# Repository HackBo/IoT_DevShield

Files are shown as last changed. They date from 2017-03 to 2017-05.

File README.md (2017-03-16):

# A Developement Shield for IoT proyects

A shield that include Sensors, Actuators And Comm Modules 'ready to work'.

The shield use the 'Arduino Socket' that accomplish the compatibility not only with Arduino boards also many other boards that use the 
same 'Arduino Socket' form.

The list of the actual components are:

## Sensors
 
 * MMA8452Q (Accelerometer)
 * LM35 (Temperature)
 * DHT11* (Humidity And Temperature)
 * SS39AT (Hall Effect)
 * SS351AT (Hall Effect)
 * LDR (Light)
 * Potenciometer
 * Switch

## Actuators

 * RGB LED
 * Buzzer
 * Rele
 * High Power Mosfet
 * Servo Motor*
 * LCD OLED*

## COMM Modules

 * HC05 (Bluetooth)
 * TSOP(IR Rx)
 * IR LED (IR Tx)
 * ESP-01* (WiFi)
 * NRF24L01+* (2.4GHz RF)

## Others

 * 24LC256 (EEPROM 256Kb)
 * DS1307 (RTC)

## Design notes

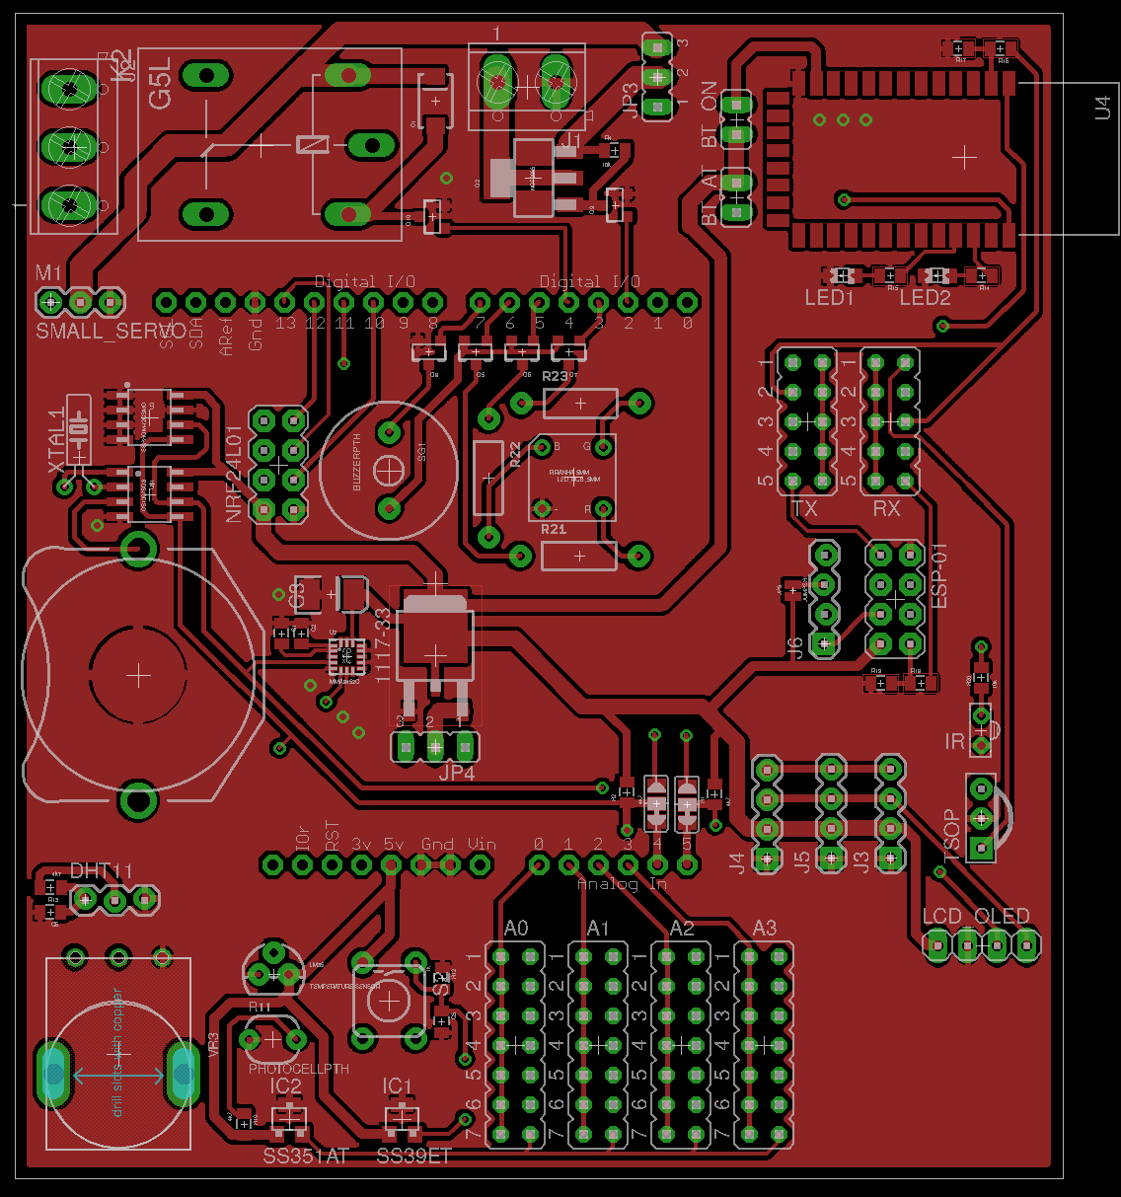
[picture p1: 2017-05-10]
img/Impreso_top.png

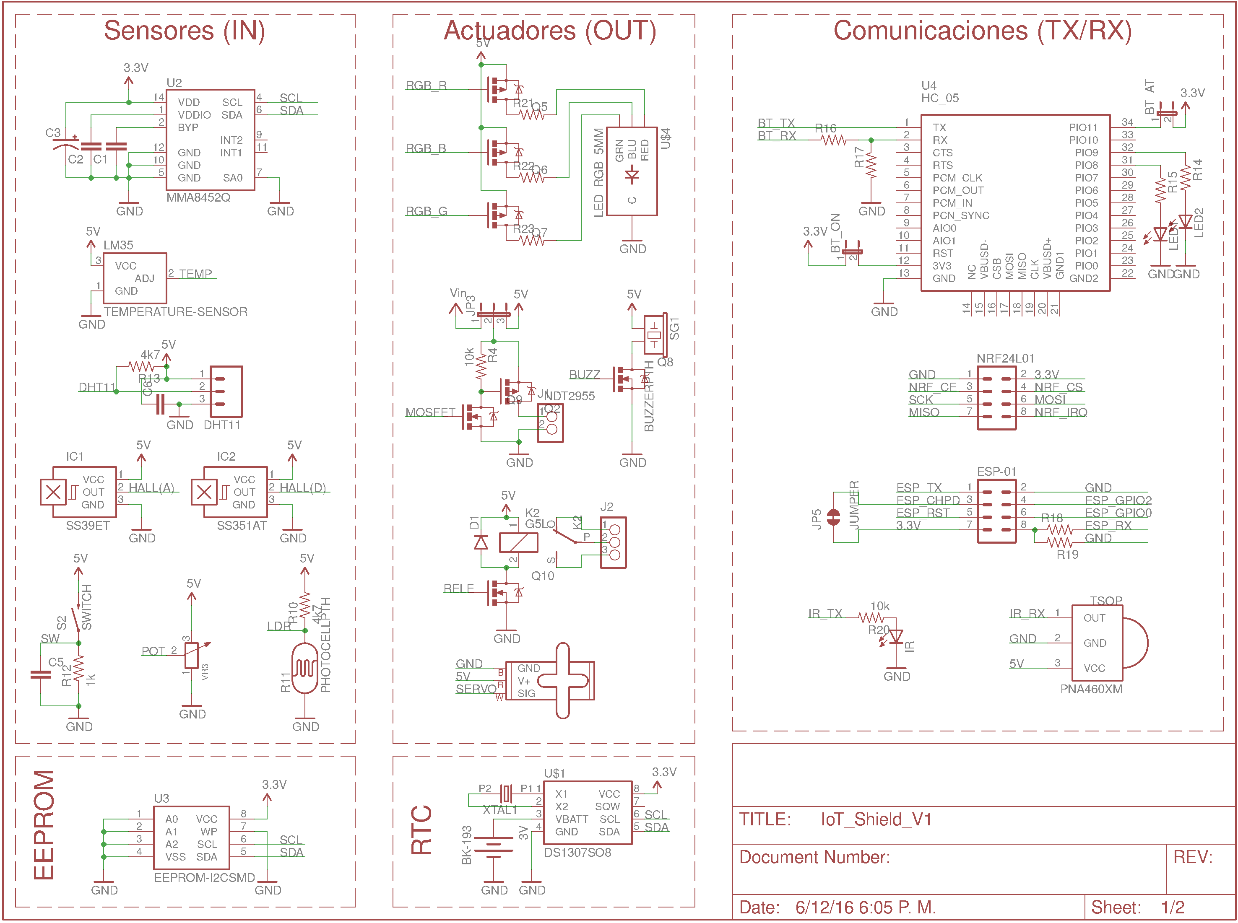
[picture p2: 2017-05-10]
img/Esquematico_Hoja1.png

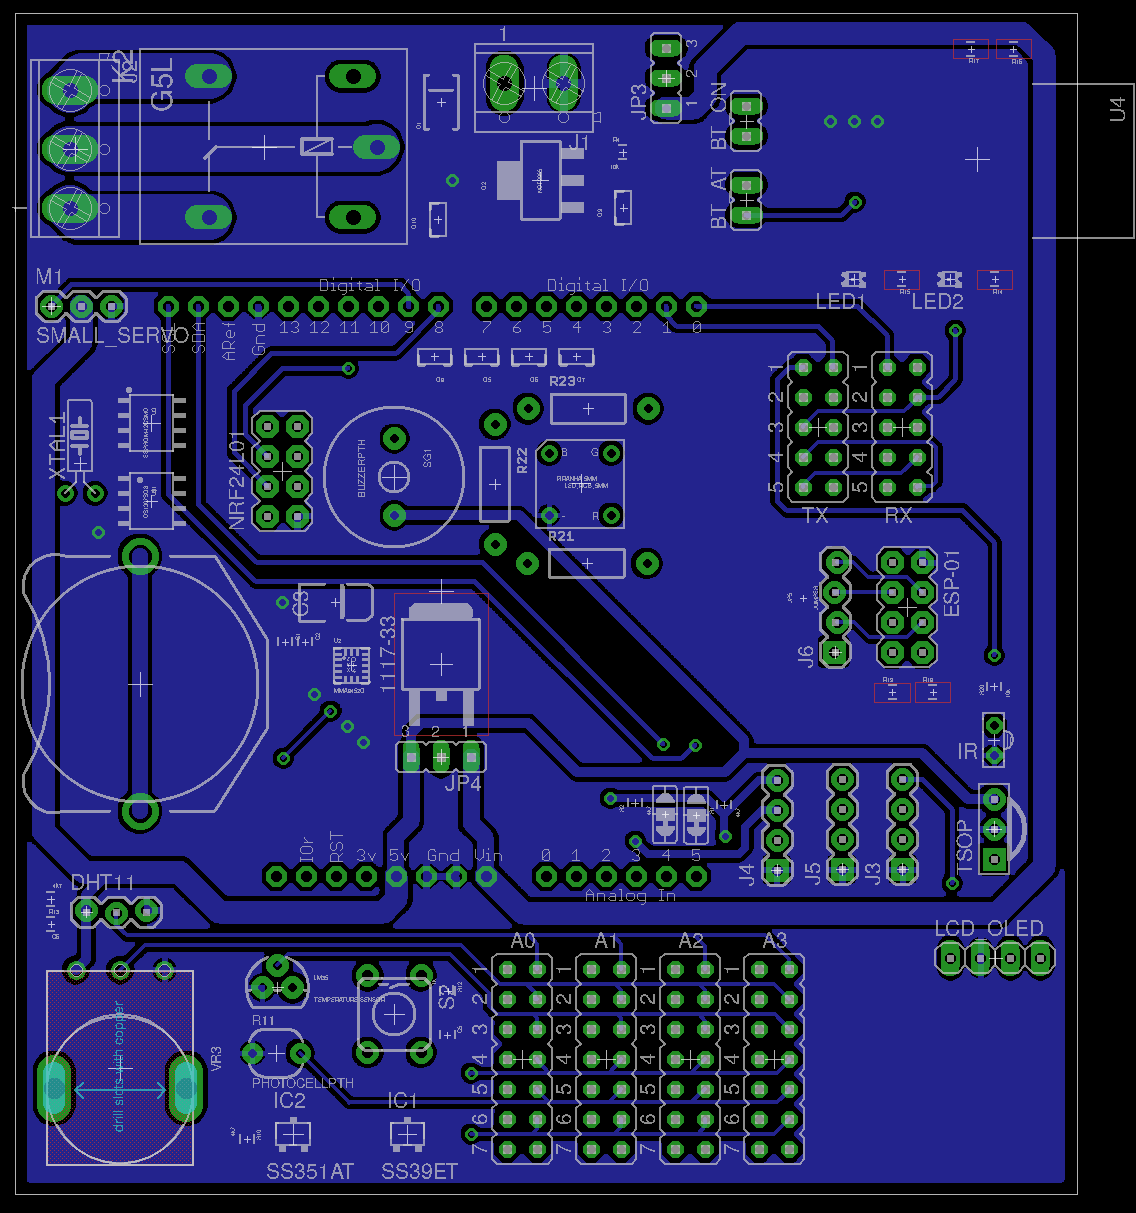
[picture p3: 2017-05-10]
img/Impreso_bottom.png

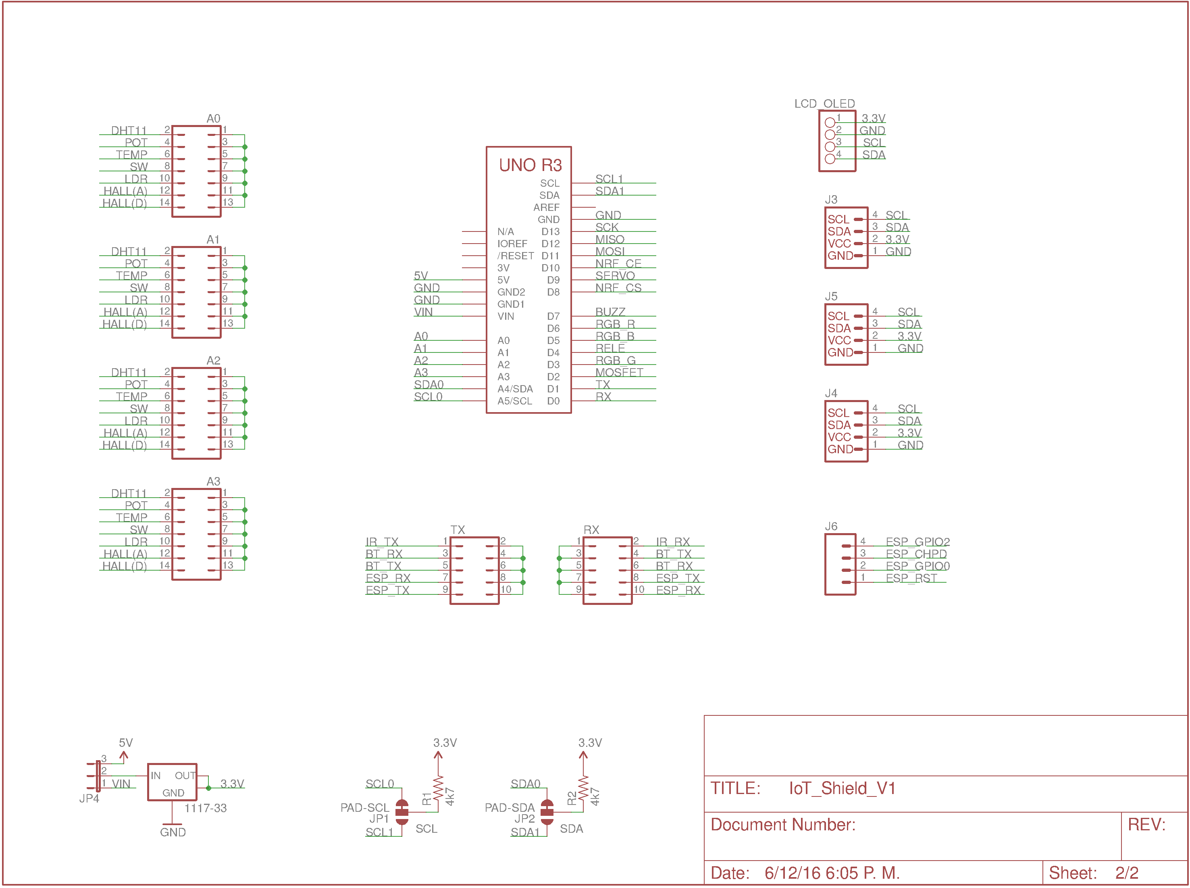
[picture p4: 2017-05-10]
img/Esquematico_Hoja2.png

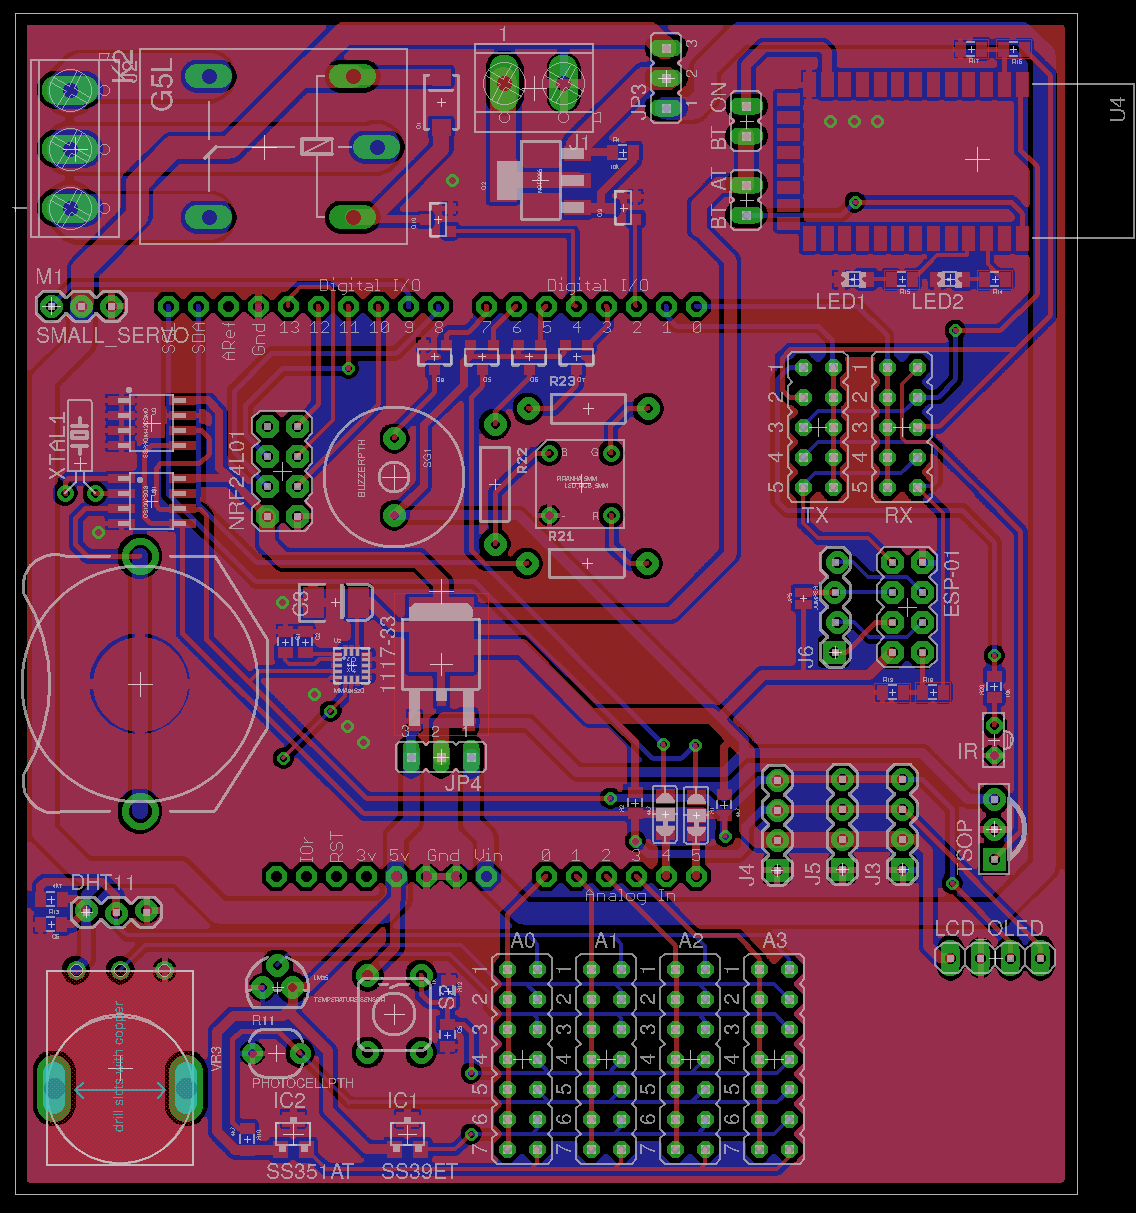
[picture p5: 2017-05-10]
img/Impreso_all.png

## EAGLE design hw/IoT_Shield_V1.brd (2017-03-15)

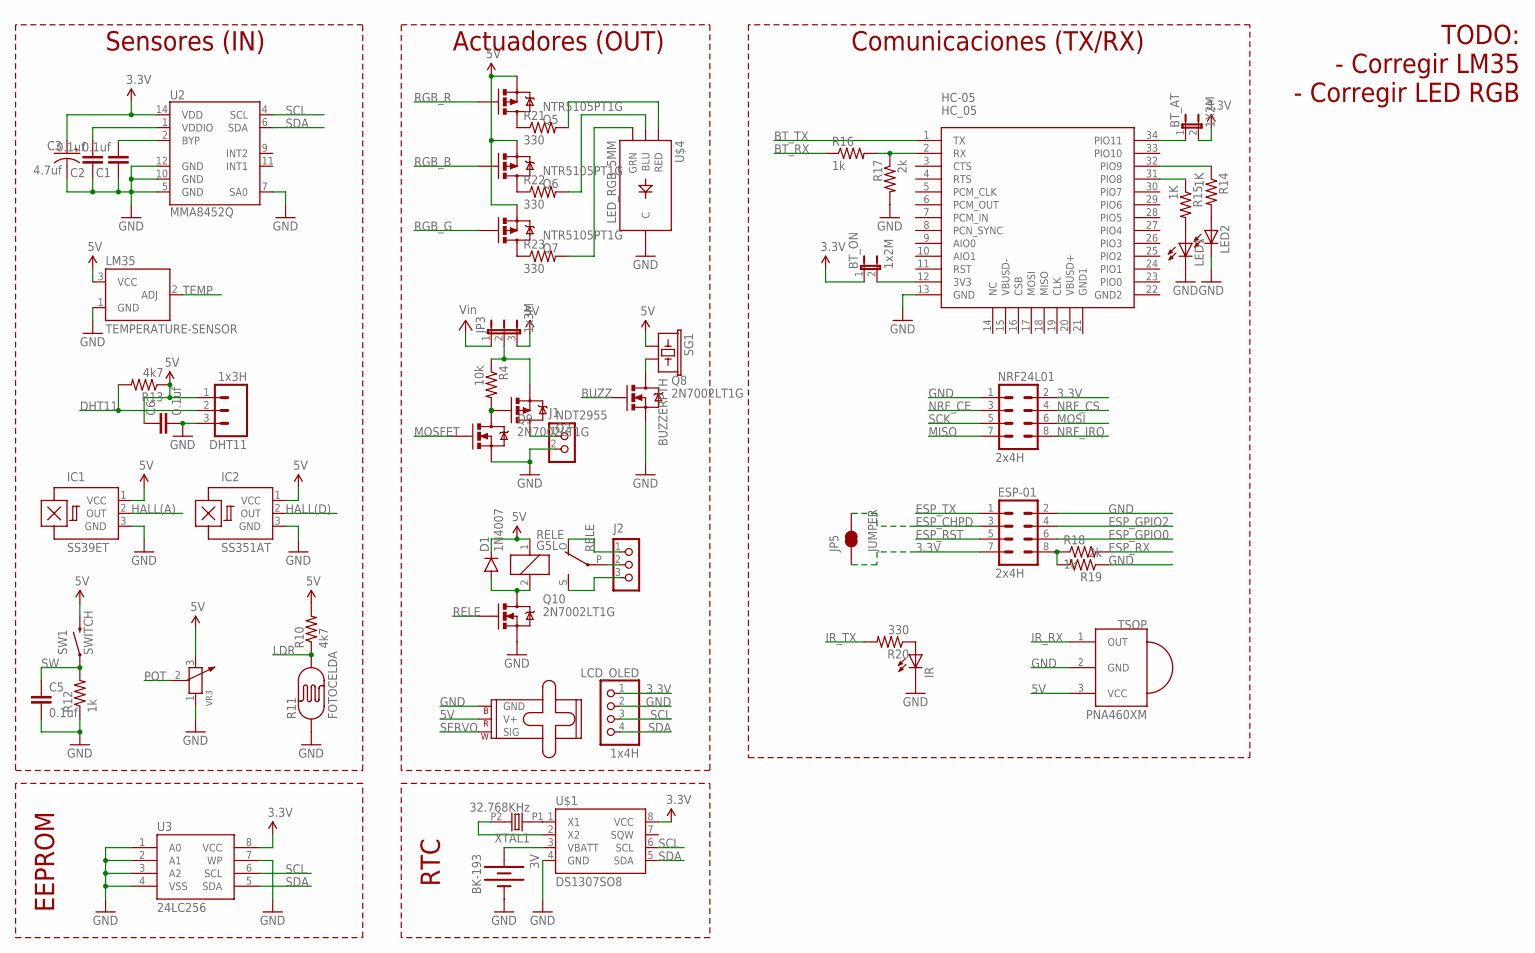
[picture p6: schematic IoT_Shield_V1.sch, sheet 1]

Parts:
3V: BK-193; BATTERY-20MMTH
BT_AT: 1X2M; JP1
BT_ON: 1x2M; JP1
C1, C2, C5, C6: 0.1uf; 0805
C3: 4.7uf; EIA3528-KIT
D1: 1N4007; SMA-DIODE
DHT11: 1x3H; 1X03_LOCK
ESP-01: 2x4H; 2X4
HC-05: HC_05; BLUETOOTH_SMD
IC1: SS39ET; SOT23-W
IC2: SS351AT; SOT23-W
IR: LEDIRL80A; IRL80A
J1: CON_TERMINAL_BLOCK_02-5MM; TERMINAL_BLOCK_2P_5
J2: CON_TERMINAL_BLOCK_03-5MM; TERMINAL_BLOCK_3P_5
JP3: 1x3M; JP2
JP5: JUMPER; PAD-JUMPER-2-NC_BY_TRACE_NO_SILK
LCD_OLED: 1x4H; 1X04
LED1, LED2: LEDCHIPLED_0805; CHIPLED_0805
LM35: TEMPERATURE-SENSOR; TO-92
NRF24L01: 2x4H; 2X4
Q2: NDT2955; SOT223
Q5, Q6, Q7: NTR5105PT1G; SOT23-3
Q8, Q9, Q10: 2N7002LT1G; SOT23-3
R4: 10k; 0805
R10, R13: 4k7; 0805
R11: FOTOCELDA; PHOTOCELL
R12, R16, R18: 1k; 0805
R14, R15: 1K; 0805
R17, R19: 2k; 0805
R20, R21, R22, R23: 330; 1206
RELE: G5L; G5LE
SERVO: 1X3M; 1X03
SG1: BUZZERPTH; BUZZER-12MM
SW1: SWITCH; TACTILE-PTH
TSOP: PNA460XM
U2: MMA8452Q; QFN-16_0.5MM
U3: 24LC256; SO08
U$1: DS1307SO8; SO08
U$4: LED_RGB_5MM; LED_PIRANHA_5MM
VR3: RES-ADJ'WH121-1'; ADJR2+3P-16.0X12.0X18.0MM
XTAL1: 32.768KHz; TC-26

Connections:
3.3V: BT_AT.2, BT_ON.1, C3.A (+), ESP-01.7, JP5.1, LCD_OLED.1, NRF24L01.2, U2.14 (VDD), U3.8 (VCC), U$1.8 (VCC); also elsewhere on the board
5V: C6.1, D1.C, DHT11.1, IC1.1 (VCC), IC2.1 (VCC), JP3.3, LM35.3 (VCC), Q5.2 (S), Q6.2 (S), Q7.2 (S), R10.2, R13.1, RELE.1, SERVO.2 (V+), SG1.+ (1), SW1.3 (2), TSOP.3 (VCC), VR3.3; also elsewhere on the board
BT_RX: R16.1; also elsewhere on the board
BT_TX: HC-05.1 (TX); also elsewhere on the board
BUZZ: Q8.1 (G); also elsewhere on the board
DHT11: DHT11.2, R13.2; also elsewhere on the board
ESP_CHPD: ESP-01.3, JP5.2; also elsewhere on the board
ESP_GPIO0: ESP-01.6; also elsewhere on the board
ESP_GPIO2: ESP-01.4; also elsewhere on the board
ESP_RST: ESP-01.5; also elsewhere on the board
ESP_RX: R18.2; also elsewhere on the board
ESP_TX: ESP-01.1; also elsewhere on the board
GND: 3V.P1- (-), C1.1, C2.1, C3.C (-), C5.2, C6.2, DHT11.3, ESP-01.2, HC-05.13 (GND), IC1.3 (GND), IC2.3 (GND), IR.K (C), J1.2, LCD_OLED.2, LED1.C, LED2.C, LM35.1 (GND), NRF24L01.1, Q8.2 (S), Q9.2 (S), Q10.2 (S), R11.1, R12.1, R17.2, R19.1, SERVO.3 (GND), TSOP.2 (GND), U2.5 (GND), U2.7 (SA0), U2.10 (GND), U2.12 (GND), U3.1 (A0), U3.2 (A1), U3.3 (A2), U3.4 (VSS), U3.7 (WP), U$1.4 (GND), U$4.- (C), VR3.1; also elsewhere on the board
HALL(A): IC1.2 (OUT); also elsewhere on the board
HALL(D): IC2.2 (OUT); also elsewhere on the board
IR_RX: TSOP.1 (OUT); also elsewhere on the board
IR_TX: R20.2; also elsewhere on the board
LDR: R10.1, R11.2; also elsewhere on the board
MISO: NRF24L01.7; also elsewhere on the board
MOSFET: Q9.1 (G); also elsewhere on the board
MOSI: NRF24L01.6; also elsewhere on the board
unnamed: U$1.2 (X2), XTAL1.P2 (2)
unnamed: U$1.1 (X1), XTAL1.P1 (1)
unnamed: 3V.P2+ (+), 3V.P3+ (+), U$1.3 (VBATT)
unnamed: C1.2, U2.2 (BYP)
unnamed: C2.2, U2.1 (VDDIO)
unnamed: J1.1, Q2.2 (D), Q2.4 (D)
unnamed: Q8.3 (D), SG1.- (2)
unnamed: Q2.1 (G), Q9.3 (D), R4.2
unnamed: D1.A, Q10.3 (D), RELE.2
unnamed: R23.2, U$4.G (GRN)
unnamed: R22.2, U$4.B (BLU)
unnamed: R21.2, U$4.R (RED)
unnamed: JP3.2, Q2.3 (S), R4.1
unnamed: BT_ON.2, HC-05.12 (3V3)
unnamed: HC-05.32 (PIO9), R14.1
unnamed: HC-05.31 (PIO8), R15.1
unnamed: LED1.A, R15.2
unnamed: LED2.A, R14.2
unnamed: HC-05.2 (RX), R16.2, R17.1
unnamed: ESP-01.8, R18.1, R19.2
unnamed: Q5.3 (D), R21.1
unnamed: BT_AT.1, HC-05.34 (PIO11)
unnamed: Q6.3 (D), R22.1
unnamed: Q7.3 (D), R23.1
unnamed: IR.A, R20.1
NRF_CE: NRF24L01.3; also elsewhere on the board
NRF_CS: NRF24L01.4; also elsewhere on the board
NRF_IRQ: NRF24L01.8
POT: VR3.2; also elsewhere on the board
RELE: Q10.1 (G); also elsewhere on the board
RELE_COMM: J2.2, RELE.P
RELE_NC: J2.1, RELE.O
RELE_NO: J2.3, RELE.S
RGB_B: Q6.1 (G); also elsewhere on the board
RGB_G: Q7.1 (G); also elsewhere on the board
RGB_R: Q5.1 (G); also elsewhere on the board
SCK: NRF24L01.5; also elsewhere on the board
SCL: LCD_OLED.3, U2.4 (SCL), U3.6 (SCL), U$1.6 (SCL); also elsewhere on the board
SDA: LCD_OLED.4, U2.6 (SDA), U3.5 (SDA), U$1.5 (SDA); also elsewhere on the board
SERVO: SERVO.1 (SIG); also elsewhere on the board
SW: C5.1, R12.2, SW1.1; also elsewhere on the board
TEMP: LM35.2 (ADJ); also elsewhere on the board
VIN: JP3.1; also elsewhere on the board

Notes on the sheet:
Sensores (IN)
Actuadores (OUT)
Comunicaciones (TX/RX)
RTC
EEPROM
TODO: - Corregir LM35 - Corregir LED RGB

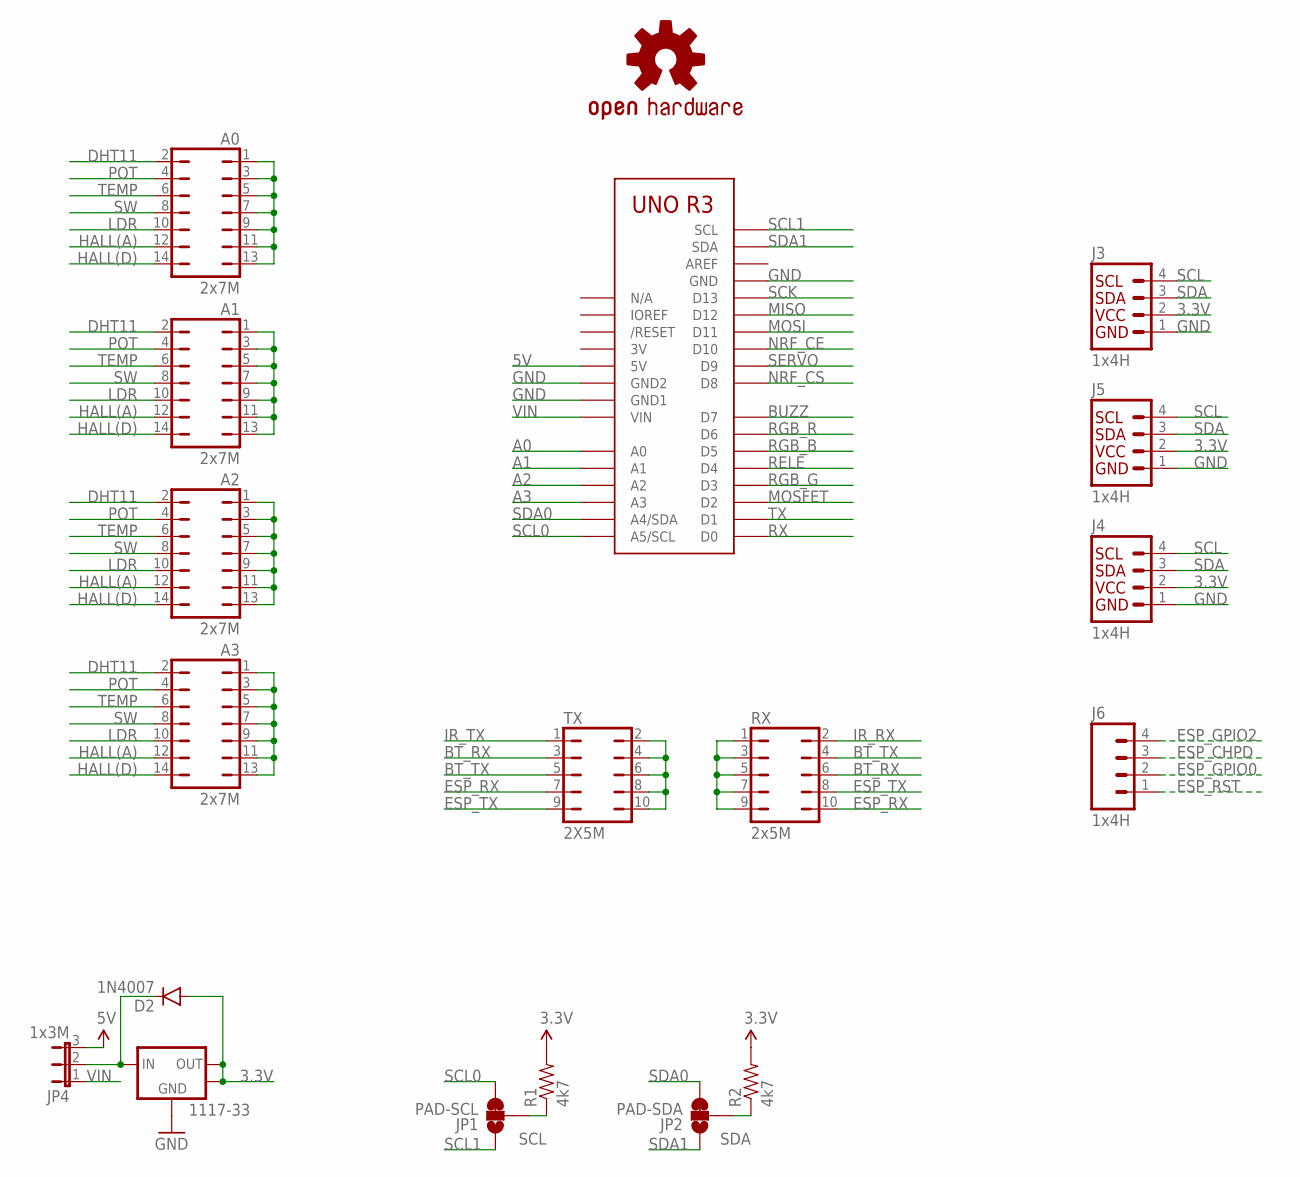
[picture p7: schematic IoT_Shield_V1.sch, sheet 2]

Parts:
1117-33: LV1117-33TO252; TO252
A0, A1, A2, A3: 2x7M; JP7Q
D2: 1N4007; SMA-DIODE
J3, J4, J5: 1x4H; 1X04
J6: 1x4H; 1X04_LOCK
JP1: PAD-SCL; PAD-JUMPER-3-2OF3_NC_BY_TRACE_YES_SILK_LARGE
JP2: PAD-SDA; PAD-JUMPER-3-2OF3_NC_BY_TRACE_YES_SILK_LARGE
JP4: 1x3M; JP2
LOGO1: OSHW-LOGOL-COPPER; OSHW-LOGO-L_COPPER
R1, R2: 4k7; 0805
RX: 2x5M; JP5Q
TX: 2X5M; JP5Q
U1: ARDUINOR3-DIMENSION; ARDUINOR3

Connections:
3.3V: 1117-33.2 (OUT), 1117-33.4 (OUT), D2.A, J3.2, J4.2, J5.2, R1.2, R2.2; also elsewhere on the board
3V: U1.3V
5V: JP4.3, U1.5V; also elsewhere on the board
A0: A0.1, A0.3, A0.5, A0.7, A0.9, A0.11, A0.13, U1.A0
A1: A1.1, A1.3, A1.5, A1.7, A1.9, A1.11, A1.13, U1.A1
A2: A2.1, A2.3, A2.5, A2.7, A2.9, A2.11, A2.13, U1.A2
A3: A3.1, A3.3, A3.5, A3.7, A3.9, A3.11, A3.13, U1.A3
BT_RX: RX.6, TX.3; also elsewhere on the board
BT_TX: RX.4, TX.5; also elsewhere on the board
BUZZ: U1.D7; also elsewhere on the board
DHT11: A0.2, A1.2, A2.2, A3.2; also elsewhere on the board
ESP_CHPD: J6.3; also elsewhere on the board
ESP_GPIO0: J6.2; also elsewhere on the board
ESP_GPIO2: J6.4; also elsewhere on the board
ESP_RST: J6.1; also elsewhere on the board
ESP_RX: RX.10, TX.7; also elsewhere on the board
ESP_TX: RX.8, TX.9; also elsewhere on the board
GND: 1117-33.1 (ADJ), J3.1, J4.1, J5.1, U1.GND, U1.GND1, U1.GND2; also elsewhere on the board
HALL(A): A0.12, A1.12, A2.12, A3.12; also elsewhere on the board
HALL(D): A0.14, A1.14, A2.14, A3.14; also elsewhere on the board
IR_RX: RX.2; also elsewhere on the board
IR_TX: TX.1; also elsewhere on the board
LDR: A0.10, A1.10, A2.10, A3.10; also elsewhere on the board
MISO: U1.D12; also elsewhere on the board
MOSFET: U1.D2; also elsewhere on the board
MOSI: U1.D11; also elsewhere on the board
unnamed: 1117-33.3 (IN), D2.C, JP4.2
NRF_CE: U1.D10; also elsewhere on the board
NRF_CS: U1.D8; also elsewhere on the board
POT: A0.4, A1.4, A2.4, A3.4; also elsewhere on the board
RELE: U1.D4; also elsewhere on the board
RGB_B: U1.D5; also elsewhere on the board
RGB_G: U1.D3; also elsewhere on the board
RGB_R: U1.D6; also elsewhere on the board
RX: RX.1, RX.3, RX.5, RX.7, RX.9, U1.D0
SCK: U1.D13; also elsewhere on the board
SCL: J3.4, J4.4, J5.4, JP1.2, R1.1; also elsewhere on the board
SCL0: JP1.3, U1.A5 (A5/SCL)
SCL1: JP1.1, U1.SCL
SDA: J3.3, J4.3, J5.3, JP2.2, R2.1; also elsewhere on the board
SDA0: JP2.3, U1.A4 (A4/SDA)
SDA1: JP2.1, U1.SDA
SERVO: U1.D9; also elsewhere on the board
SW: A0.8, A1.8, A2.8, A3.8; also elsewhere on the board
TEMP: A0.6, A1.6, A2.6, A3.6; also elsewhere on the board
TX: TX.2, TX.4, TX.6, TX.8, TX.10, U1.D1
VIN: JP4.1, U1.VIN; also elsewhere on the board

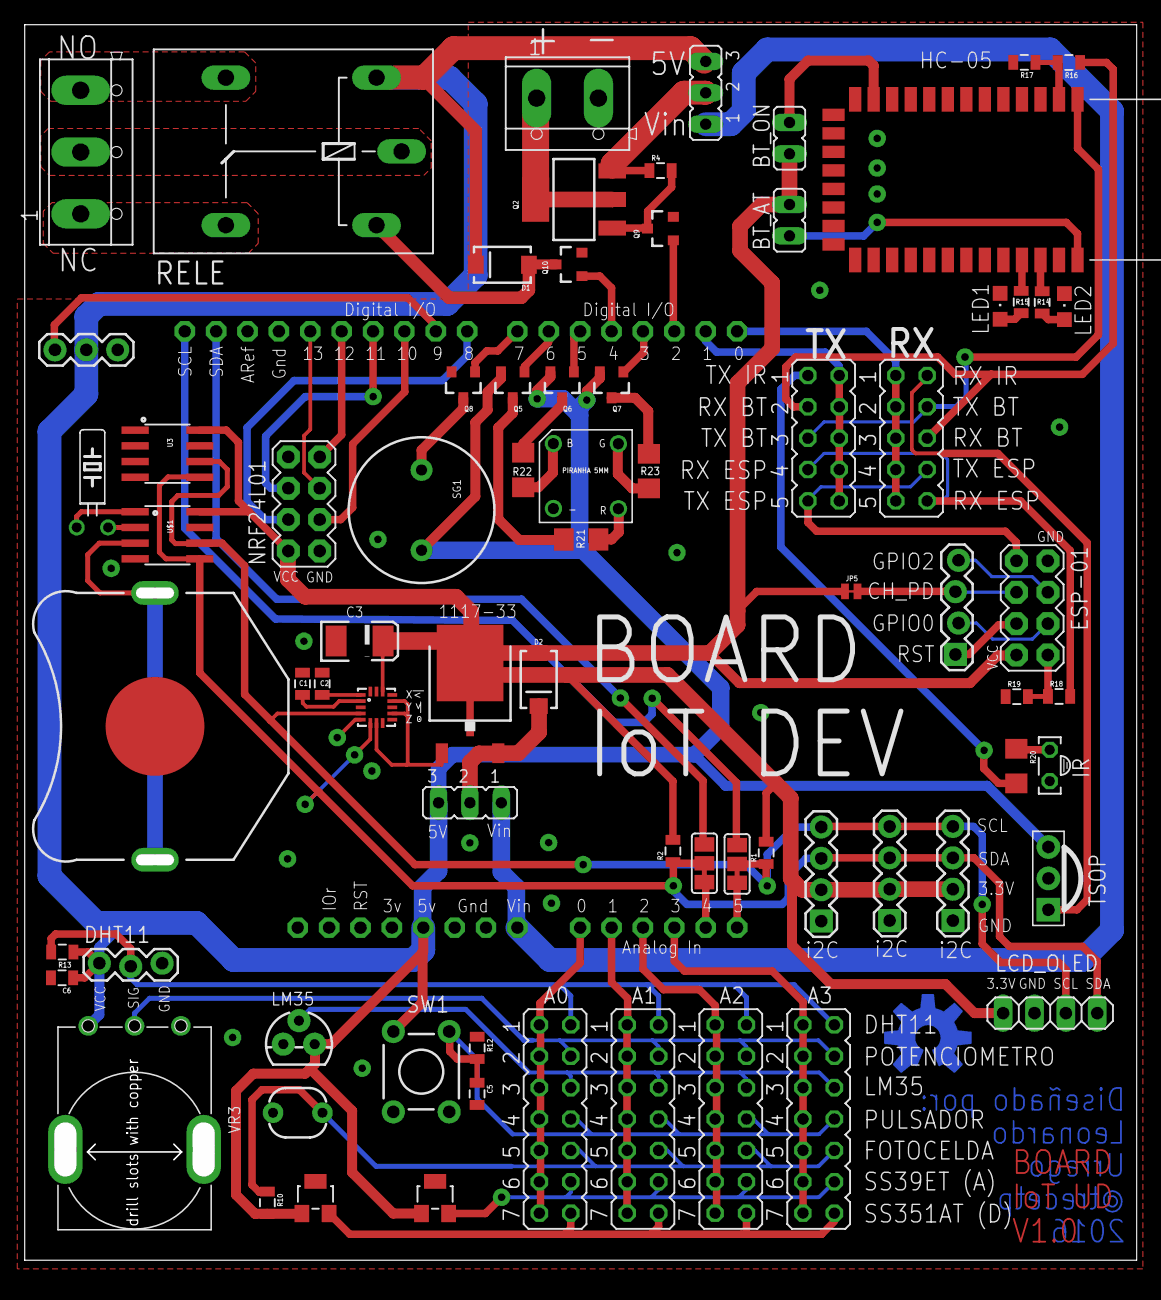
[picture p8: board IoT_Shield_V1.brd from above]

Board: 2 copper layers, 90.0 x 100.0 mm, 76 parts (1 on the bottom side), 74 nets.

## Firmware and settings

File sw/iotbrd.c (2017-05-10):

#include <Wire.h>
#include <RTClib.h>
#include <U8x8lib.h>
#include <SimpleDHT.h>
#include <Servo.h>


//Definiciones de pines

//Pines de salida
#define _OUT_LED_RGB_R_         5
#define _OUT_LED_RGB_G_         3
#define _OUT_LED_RGB_B_         6
#define _OUT_MOSFET_            2
#define _OUT_RELE_              4
#define _OUT_BUZZ_              7
#define _OUT_SERVO_             9

// Pines de Entrada
#define _IN_A0_POT_             A0
#define _IN_A2_POT_             A2
#define _IN_A0_LM35_            A0
#define _IN_A1_DHT11_           15



//Pines de Control
#define _NFR_CS_                8
#define _NFR_CE_                10

//Contantes de control
#define _LED_RGB_ON_            0
#define _LED_RGB_OFF_           1
#define _MOSFET_ON_             1
#define _MOSFET_OFF_            0
#define _BUZZ_ON_               1
#define _BUZZ_OFF_              0
#define _RELE_ON_               1
#define _RELE_OFF_              0



//MACROS
#define ledRGB_ON_R()   digitalWrite(_OUT_LED_RGB_R_, _LED_RGB_ON_)
#define ledRGB_ON_G()   digitalWrite(_OUT_LED_RGB_G_, _LED_RGB_ON_)
#define ledRGB_ON_B()   digitalWrite(_OUT_LED_RGB_B_, _LED_RGB_ON_)
#define ledRGB_OFF_R()  digitalWrite(_OUT_LED_RGB_R_, _LED_RGB_OFF_)
#define ledRGB_OFF_G()  digitalWrite(_OUT_LED_RGB_G_, _LED_RGB_OFF_)
#define ledRGB_OFF_B()  digitalWrite(_OUT_LED_RGB_B_, _LED_RGB_OFF_)

#define mosfetON()      digitalWrite(_OUT_MOSFET_, _MOSFET_ON_)
#define mosfetOFF()     digitalWrite(_OUT_MOSFET_, _MOSFET_OFF_)

#define buzzON()      digitalWrite(_OUT_BUZZ_, _BUZZ_ON_)
#define buzzOFF()     digitalWrite(_OUT_BUZZ_, _BUZZ_OFF_)

#define releON()      digitalWrite(_OUT_RELE_, _RELE_ON_)
#define releOFF()     digitalWrite(_OUT_RELE_, _RELE_OFF_)


// Define variables Globales
U8X8_SSD1306_128X64_NONAME_HW_I2C lcdi2c(U8X8_PIN_NONE);
RTC_DS1307      rtc;
SimpleDHT11     dht11;
Servo           myServo;  // create a servo object

// char daysOfTheWeek[7][12] = {"Domingo", "Lunes", "Martes", "Miercoles", "Jueves", "Viernes", "Sabado"};

void iniIOTbrdUD(){
    analogReference(INTERNAL);
    Serial.begin(9600);             // Para el debug via USB o Bluetooth

    // Configura LED
    pinMode(_OUT_LED_RGB_R_, OUTPUT);
    pinMode(_OUT_LED_RGB_G_, OUTPUT);
    pinMode(_OUT_LED_RGB_B_, OUTPUT);
    ledRGB_OFF_R();
    ledRGB_OFF_G();
    ledRGB_OFF_B();

    // Configura MOSFET
    pinMode(_OUT_MOSFET_, OUTPUT);
    mosfetOFF();

    // Configura Buzzer
    pinMode(_OUT_BUZZ_, OUTPUT);
    buzzOFF();

    // Configura Rele
    pinMode(_OUT_RELE_, OUTPUT);
    releOFF();

    // Configura Servo
    pinMode(_OUT_SERVO_, OUTPUT);
    myServo.attach(9); // attaches the servo on pin 9 to the servo object

    // Configura RTC
    rtc.begin();
    if (! rtc.isrunning()) rtc.adjust(DateTime(F(__DATE__), F(__TIME__)));

    // Configura LCD
    lcdi2c.begin();
    lcdi2c.setFont(u8x8_font_amstrad_cpc_extended_r);
    // lcdi2c.setCursor(0, 0); // x,y || [0-15 , 0-7] 16X8
    // lcdi2c.print("IoT UD");
    lcdi2c.clear();
    lcdi2c.draw2x2String(4, 1, "BOARD");
    lcdi2c.draw2x2String(3, 4, "IoT UD");
    delay(1000);
}

void demoRGB_1(){
    lcdi2c.clear();
    lcdi2c.draw2x2String(1, 1, "DEMO #1");
    lcdi2c.draw2x2String(1, 4, "LED RGB");

    ledRGB_ON_R();
    delay(2000);
    ledRGB_OFF_R();
    ledRGB_ON_G();
    delay(2000);
    ledRGB_OFF_G();
    ledRGB_ON_B();
    delay(2000);
    ledRGB_ON_R();
    delay(2000);
    ledRGB_OFF_B();
    ledRGB_ON_G();
    delay(2000);
    ledRGB_OFF_R();
    ledRGB_ON_B();
    delay(2000);
    ledRGB_OFF_B();
    ledRGB_OFF_G();
}

void demoRGB_2(){
    lcdi2c.clear();
    lcdi2c.draw2x2String(1, 1, "DEMO #2");
    lcdi2c.draw2x2String(1, 4, "LED RGB");
    int brillo = 255;
    while(brillo >= 0){
        analogWrite(_OUT_LED_RGB_R_, brillo);
        analogWrite(_OUT_LED_RGB_G_, brillo);
        analogWrite(_OUT_LED_RGB_B_, brillo);
        delay(20);
        brillo--;
    }
    brillo = 0;
    while(brillo <= 255){
        analogWrite(_OUT_LED_RGB_R_, brillo);
        analogWrite(_OUT_LED_RGB_G_, brillo);
        analogWrite(_OUT_LED_RGB_B_, brillo);
        delay(20);
        brillo++;
    }
}

void demoBuzzer(){
    lcdi2c.clear();
    lcdi2c.draw2x2String(5, 1, "DEMO");
    lcdi2c.draw2x2String(3, 4, "BUZZER");
    buzzON();
    delay(1000);
    buzzOFF();
    delay(1000);
    buzzON();
    delay(100);
    buzzOFF();
    delay(100);
    buzzON();
    delay(100);
    buzzOFF();
}

void demoRele(){
    lcdi2c.clear();
    lcdi2c.draw2x2String(5, 1, "DEMO");
    lcdi2c.draw2x2String(5, 4, "RELE");

    releON();
    delay(5000);
    releOFF();
}

void demoMosfet(){
    lcdi2c.clear();
    lcdi2c.draw2x2String(5, 1, "DEMO");
    lcdi2c.draw2x2String(4, 4, "MOSFET");

    mosfetON();
    delay(5000);
    mosfetOFF();
}

void demoSensores(){
    lcdi2c.clear();
    lcdi2c.draw2x2String(5, 1, "DEMO");
    lcdi2c.draw2x2String(0, 4, "SENSORES");
    delay(2000);
    lcdi2c.clear();

    for(uint16_t i=0; i<1000; i++){
        // lcdi2c.clear();
        lcdi2c.setCursor(0, 0);
        DateTime now = rtc.now();
        lcdi2c.print(now.year(), DEC);
        lcdi2c.print('/');
        lcdi2c.print(now.month(), DEC);
        lcdi2c.print('/');
        lcdi2c.print(now.day(), DEC);
        lcdi2c.setCursor(0, 1);
        lcdi2c.print(now.hour(), DEC);
        lcdi2c.print(':');
        lcdi2c.print(now.minute(), DEC);
        lcdi2c.print(':');
        lcdi2c.print(now.second(), DEC);

        Serial.print(now.year(), DEC);
        Serial.print('/');
        Serial.print(now.month(), DEC);
        Serial.print('/');
        Serial.println(now.day(), DEC);
        Serial.print(now.hour(), DEC);
        Serial.print(':');
        Serial.print(now.minute(), DEC);
        Serial.print(':');
        Serial.println(now.second(), DEC);

        lcdi2c.setCursor(0, 3);
        lcdi2c.print("*C: ");
        Serial.print("*C: ");
        uint16_t tempC = analogRead(_IN_A0_LM35_) / 9.31;
        lcdi2c.print(tempC);
        Serial.println(tempC);

        lcdi2c.setCursor(0, 4);
        lcdi2c.print("%H: ");
        Serial.print("%H: ");
        byte humidity = 0;
        byte temperature = 0;
        dht11.read(_IN_A1_DHT11_, &temperature, &humidity, NULL);
        lcdi2c.print((int)humidity);
        Serial.println((int)humidity);


        lcdi2c.setCursor(0, 5);
        uint16_t potVal = analogRead(_IN_A2_POT_); // read the value of the potentiometer
        // print out the value to the serial monitor
        lcdi2c.print("potVal: ");
        lcdi2c.print(potVal);
        // scale the numbers from the pot
        uint16_t angle = map(potVal, 0, 1023, 0, 179);
        // print out the angle for the servo motor
        myServo.write(angle);



        delay(500);
    }
}

void setup() {
    iniIOTbrdUD();
}



void loop() {

    demoRGB_1();
    demoRGB_2();
    demoBuzzer();
    demoRele();
    demoMosfet()
;    demoSensores();

}

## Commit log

2017-03-15 First Version
    [IoT_Shield_V1.brd, IoT_Shield_V1.sch]
2017-05-10 Algunas imagenes de Archivo
2017-05-10 Codigo de ejemplo para probar la tarjeta

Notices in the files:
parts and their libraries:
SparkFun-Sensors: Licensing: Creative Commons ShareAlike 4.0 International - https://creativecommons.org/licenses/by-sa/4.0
